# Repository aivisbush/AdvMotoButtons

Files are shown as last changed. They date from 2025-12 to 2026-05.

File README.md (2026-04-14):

# Bush's Moto Buttons v1.0
### Thanks to [the original author](https://github.com/joncox123/MotoButtons2/tree/main) for free sourcing this amazing piece of art, especially the dev board wiring and the code part! So, I needed some modifications to it to move forward to perfection. To continue supporting enduro, offroad, adventure enthusiasts who can also tinker with electronics, and build a relatively inexpensive alternative to moto buttons, I also want to share my work.

### My changes:
- LED brightness control by holding the A key
- Added possibility to add any color or brightness (within code)
- Separate key A and Joystick Center key codes (in original code they were the same)
- DMD2 mode color changed to blue (looks cooler)
- Button special function changes (will be described later)
- Added reset option by holding A,B,C keys. This is a workaround for the issue when Bluetooth auto-pairing did not work anymore, e.g., when the moto buttons are powered on, auto-connection to the phone/tablet does not work

### Design:

| | |
| --- | --- |
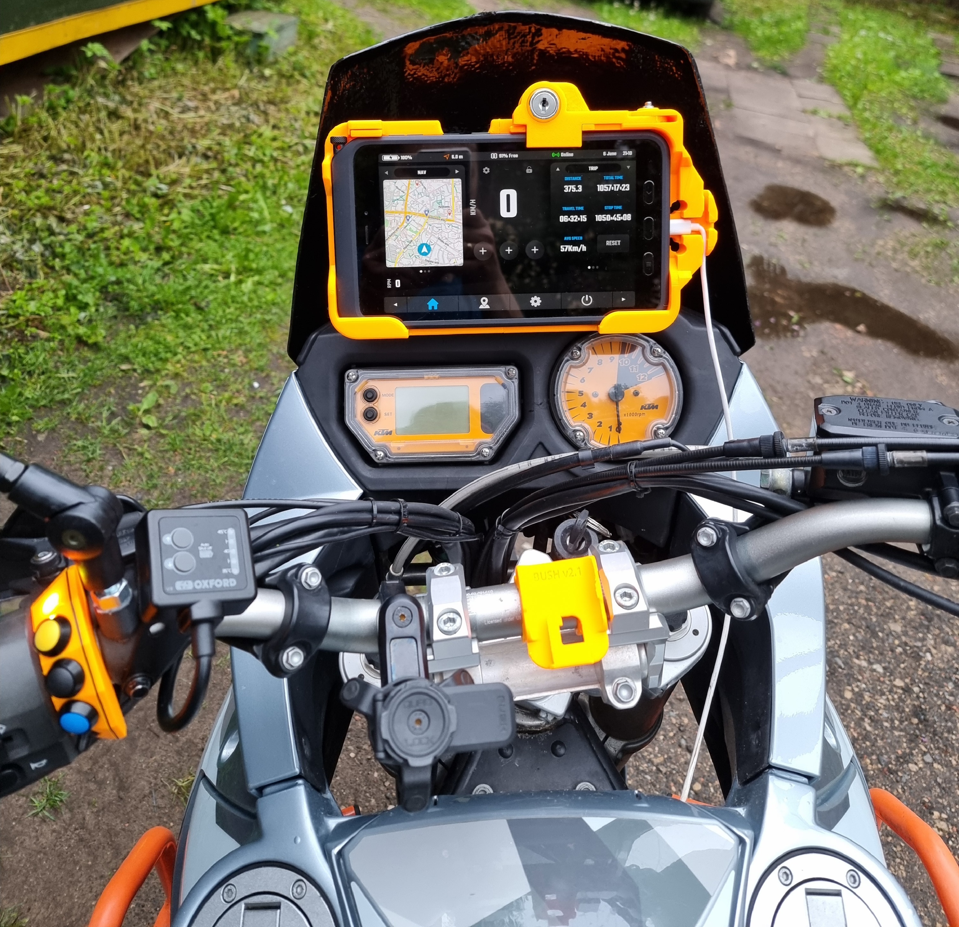
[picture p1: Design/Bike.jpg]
Bike
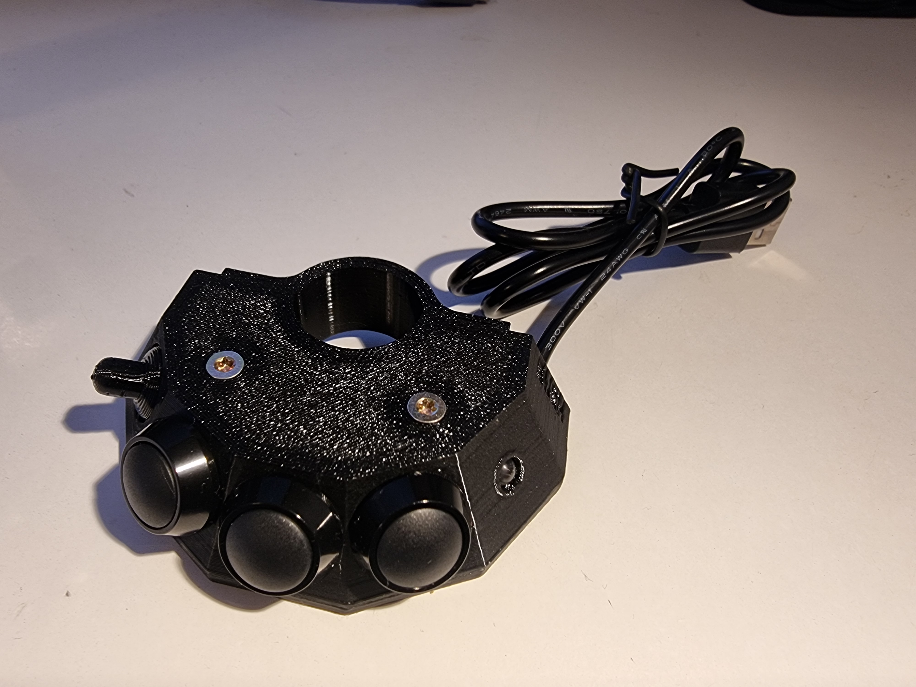
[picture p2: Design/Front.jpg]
Front
|  |  |
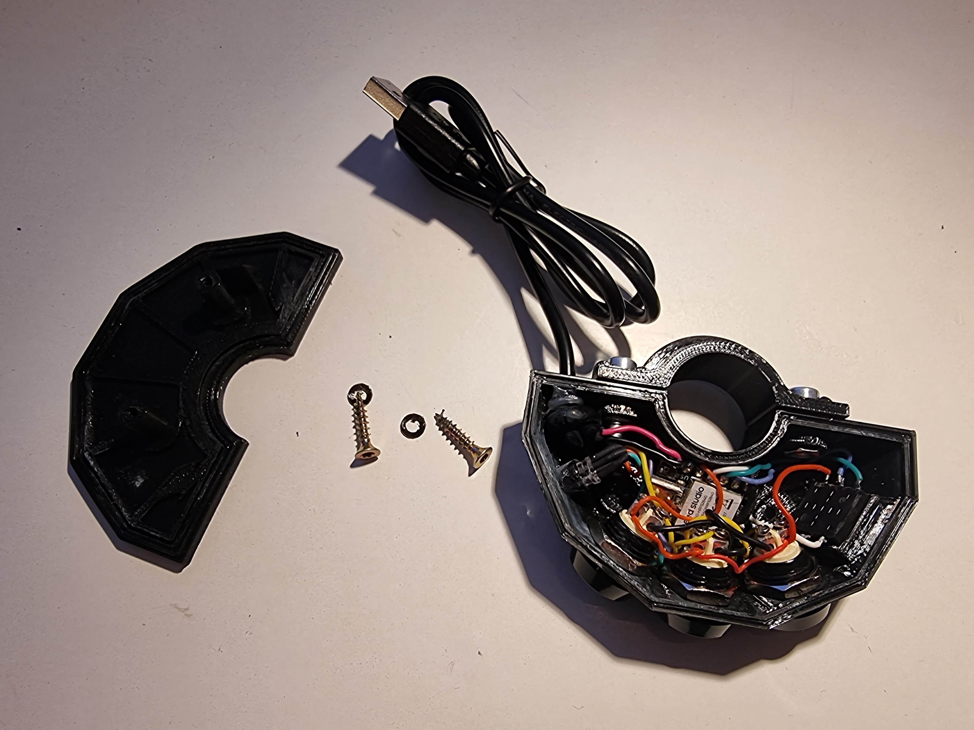
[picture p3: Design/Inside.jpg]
Inside
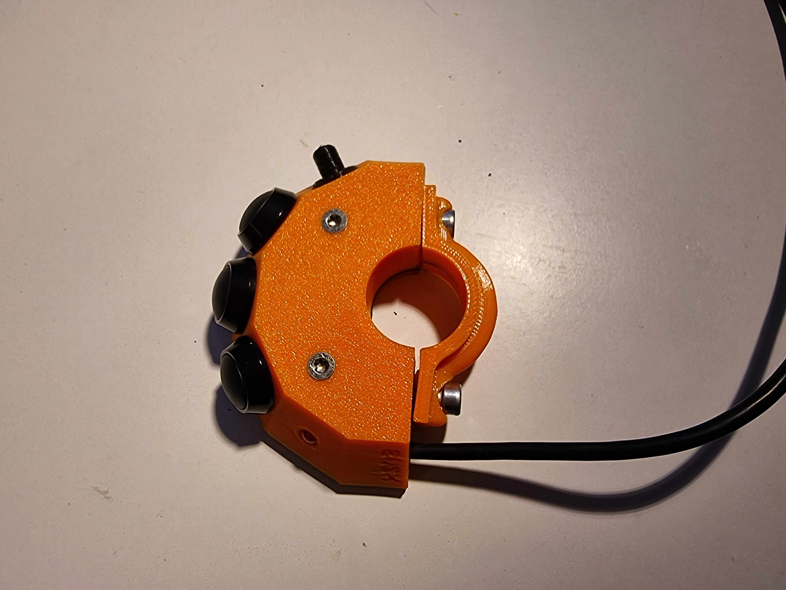
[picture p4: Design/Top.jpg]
Top
|  |  |

### Parts:
- Some old USB-A cable for power and other wires
- Seeed Studio XIAO nRF52840 series (I used Seeed Studio XIAO nRF52840 Sense)
- 3x waterproof buttons (I used V12B-10N-A)
- 5-way joystick (I used JS5208)
- RGB LED common **anode ONLY** (I used OSTAMA5B31A) **Do not use common cathode, I already burned 2x Seeed boards to realize that**
- 3D printed case with some screws (the case is waterproof enough to hold rain and some submersion. I've already been using it for 1 year, no issues. But use some super glue on the TPU gasket and glue gun around holes from inside). All TPU and PETG (or alternative filament) STLs are in 3D folder.

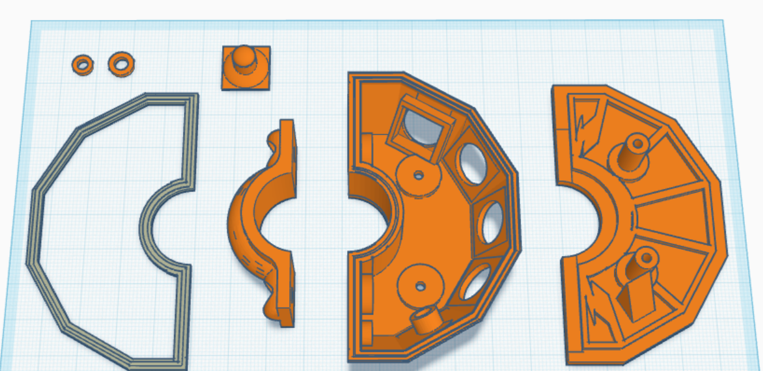
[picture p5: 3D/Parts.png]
Parts


## User Manual
The device has:
- 3x buttons and 1x joystick as inputs
- 1x LED indicator (for understanding what is going on)

Standard button functionality by mode:

`DMD2` mode (**NOTE**: bound buttons manually in Settings -> Setup Remote Controller):
- Button A short press or hold - `F6` / oom in
- Button B short press or hold - `F7` / zoom out
- Button C short press or hold - `Enter` / follow toggle (focus)
- Joystick Up, Down, Left, Right - Arrow keys
- Joystick Middle press - `F8`

`OsmAnd` mode:
- Button A short press or hold - `+` / zoom in
- Button B short press or hold - `-` / zoom out
- Button C short press or hold - `C` / move to my location (focus)
- Joystick Up, Down, Left, Right - Arrow keys
- Joystick Middle press - Unbound

`Media` mode:
- Button A short press or hold - Play / Pause
- Button B short press or hold - Screen brightness up
- Button C short press or hold - Screen brightness down
- Joystick Up - Volume up
- Joystick Down - Volume down
- Joystick Left - Previous track
- Joystick Right - Next track
- Joystick Middle press - Mute

Special functions:
- Hold joystick up button when powering on device, it will select correct orientation
- Button A+B long press - LED brightness changes; hold it until you are satisfied and release
- Button B+C long press - Mode change: DMD2 (blue) -> OsmAnd (green) -> Media (magenta)
- Button A+B+C long press (5 secs) - Erase FS. This is a workaround to get BT auto-connect working again
- Button A+C long press (5 secs) - Enter DFU mode (for programming)

## Wiring
If something is unclear, please read [the original author's manuals](https://github.com/joncox123/MotoButtons2/tree/main/ConstructionGuide).
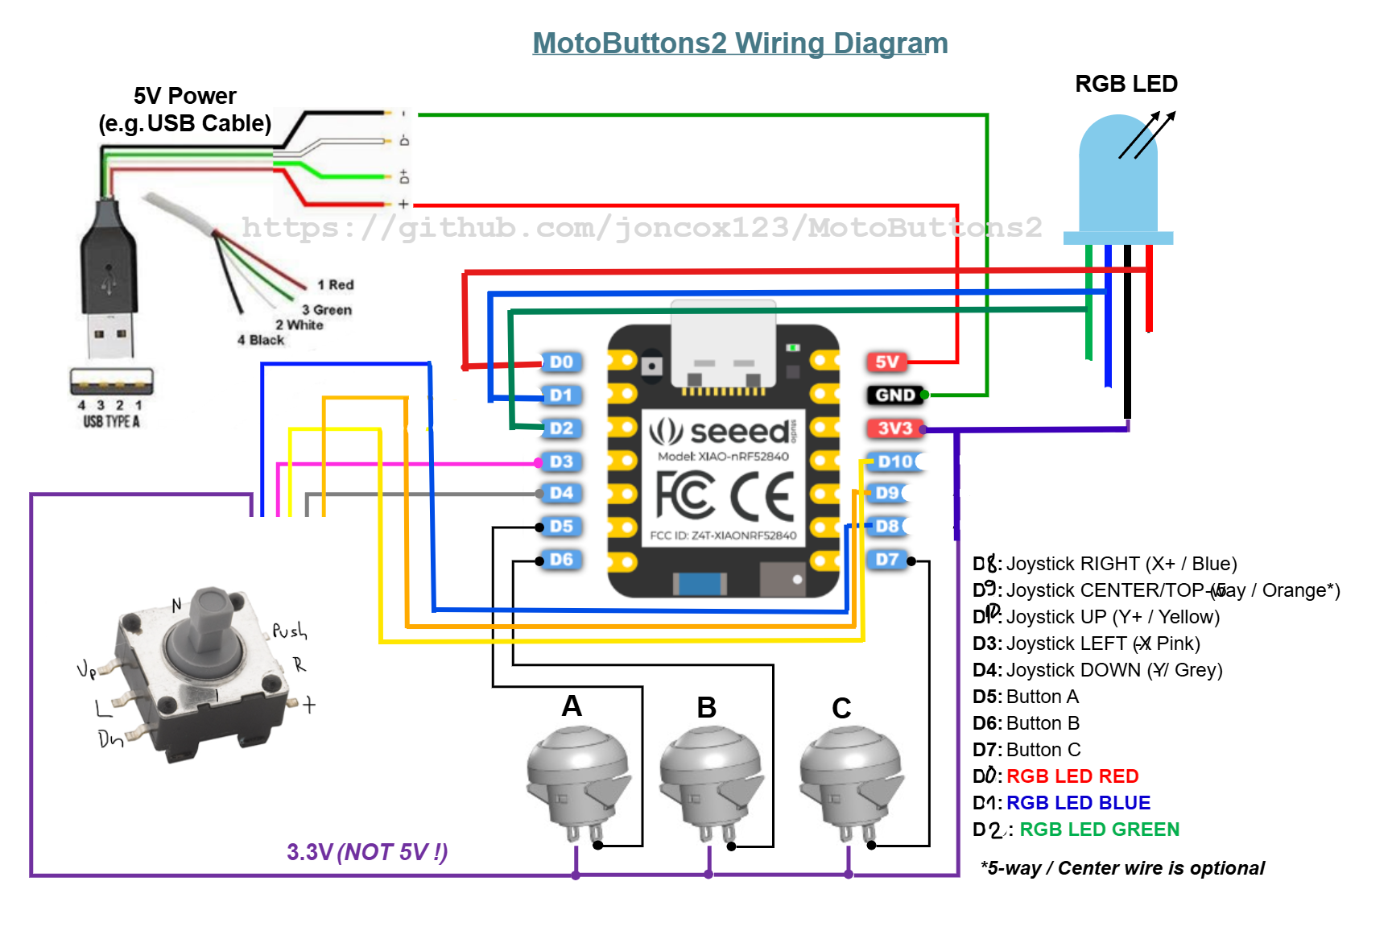
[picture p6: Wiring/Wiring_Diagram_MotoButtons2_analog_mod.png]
Wiring Diagram


## Code
Please read [the original author's manuals](https://github.com/joncox123/MotoButtons2/tree/main/Programming) on how to do that.

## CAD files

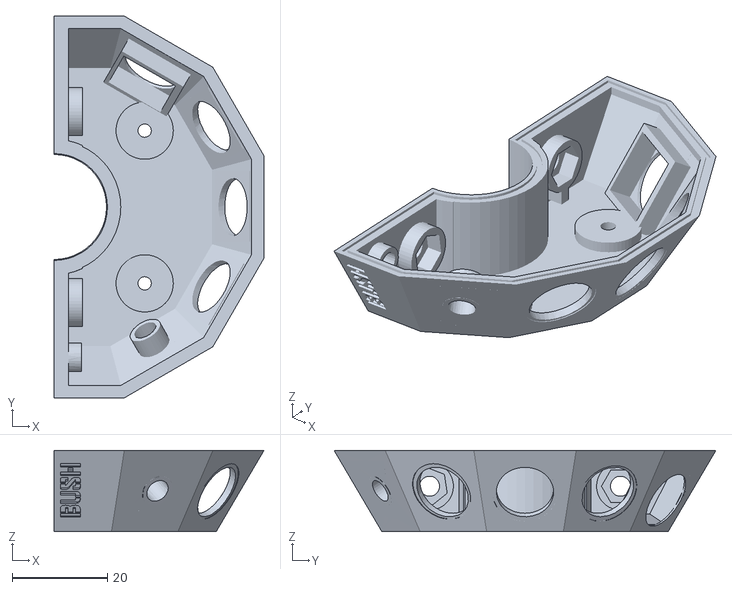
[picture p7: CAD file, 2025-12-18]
3D/Case_main_PETG.stl
44.0 x 80.0 x 17.0

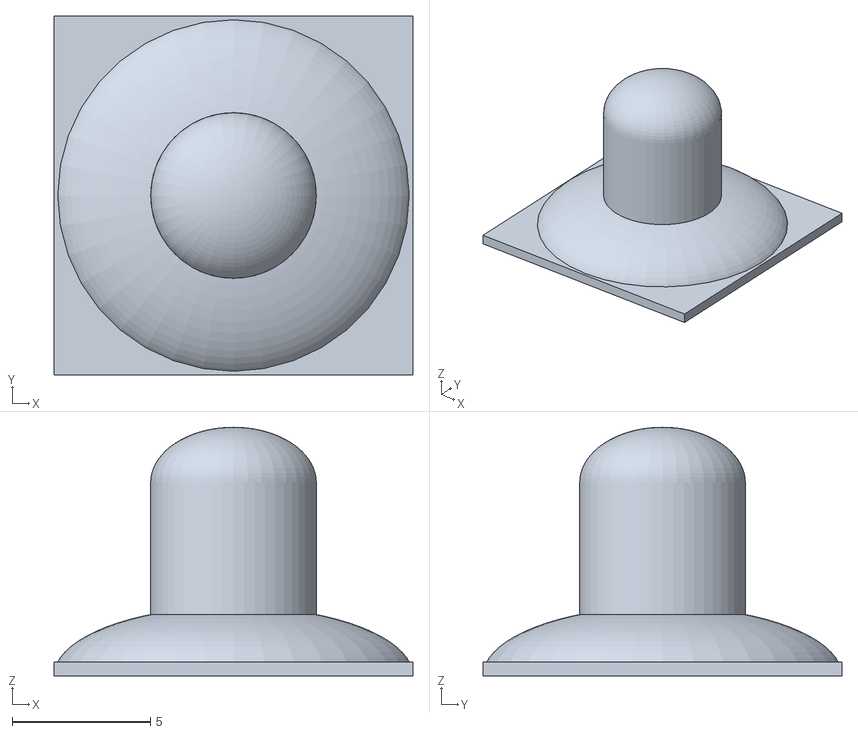
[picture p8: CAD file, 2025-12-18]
3D/Joystick_cover_TPU.stl
13.0 x 13.0 x 9.00

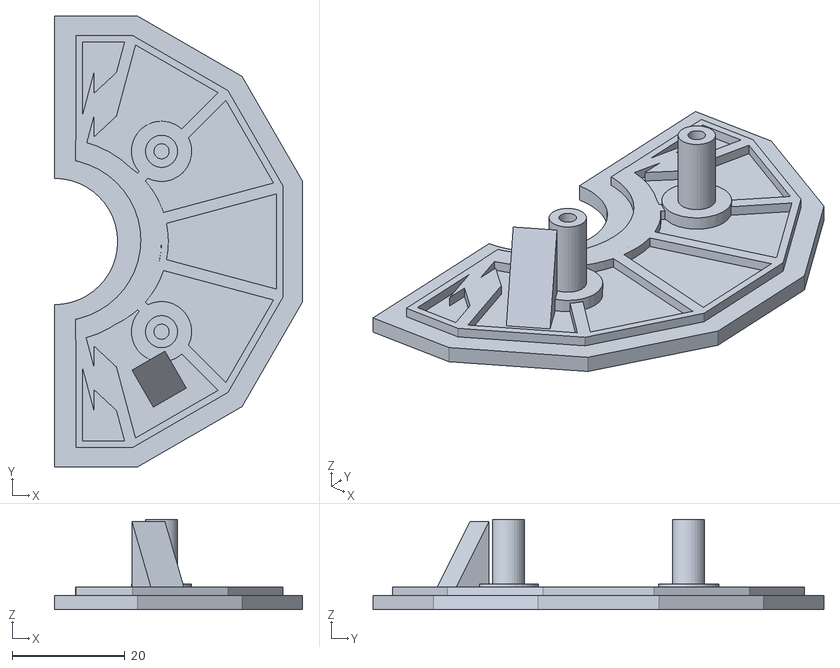
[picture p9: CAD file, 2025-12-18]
3D/Case_top_PETG.stl
44.0 x 80.0 x 16.0

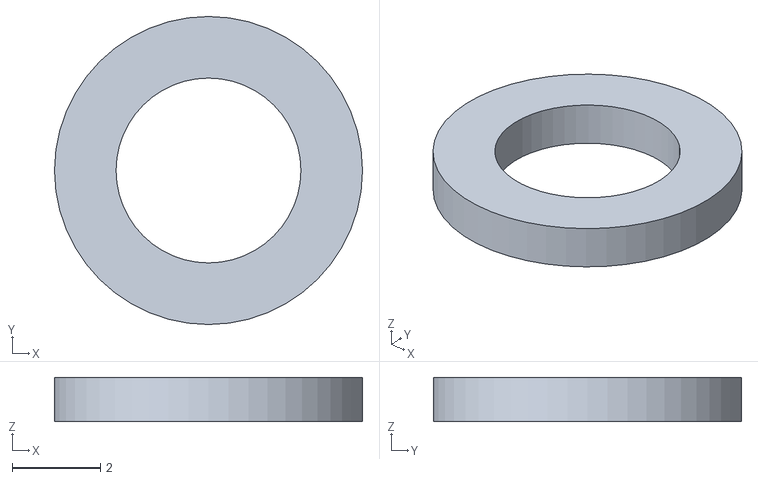
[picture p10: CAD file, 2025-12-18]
3D/SpacerA_TPU.stl
7.00 x 7.00 x 1.00

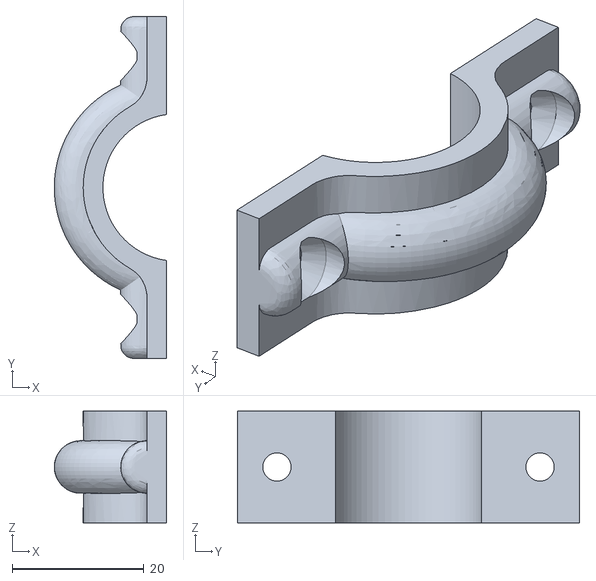
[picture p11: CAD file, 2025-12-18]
3D/Handlebar_back_PETG.stl
17.1 x 52.0 x 17.0

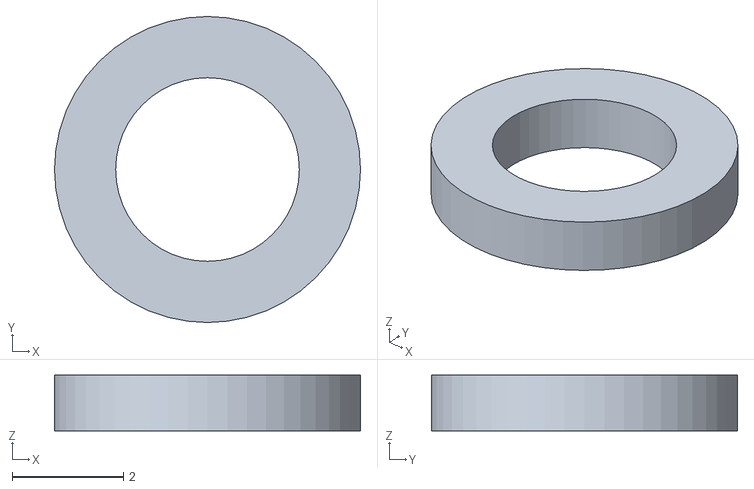
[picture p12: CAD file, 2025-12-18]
3D/SpacerB_TPU.stl
5.50 x 5.50 x 1.00

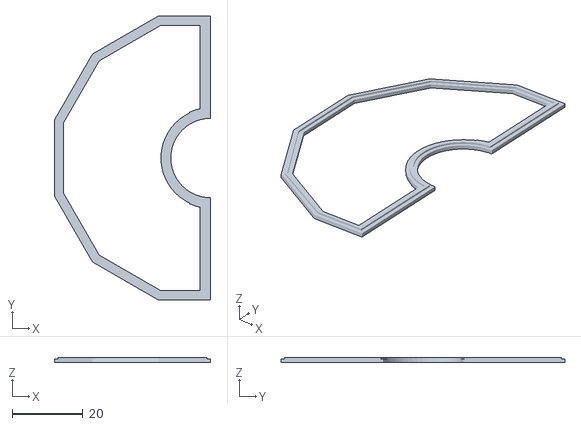
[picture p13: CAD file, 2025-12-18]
3D/Gasket_TPU.stl
44.0 x 80.0 x 1.50

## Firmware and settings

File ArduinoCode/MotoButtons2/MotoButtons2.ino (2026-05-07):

/*********************************************************************
License: GNU GENERAL PUBLIC LICENSE; Version 3, 29 June 2007
Version: 2.0 with support for the following modes: DMD2, OsmAnd, media (music)
Device: Seeed XIAO ESP32-C6 (MotoButtons 2)
*********************************************************************/
#include <HijelHID_BLEKeyboard.h>
#include <Preferences.h>
#include <stdlib.h>

// Enable serial debugging (turn this off if not connected to PC)
#define DEBUG false

// How long to wait until the reset combo is activated
#define MODE_RESET_MS 5000

// Orientation of controller
#define DEFAULT_BUTTON_MAP 3
#define STARTUP_ORIENTATION_WINDOW_MS 500
uint8_t buttonOrientation = DEFAULT_BUTTON_MAP;

/*----- Persistent Storage -----*/
// This is used to store settings, such as the last mode.
Preferences preferences;
const char SETTINGS_NAMESPACE[] = "MotoButtons";

// BLE configuration
#define BLE_TX_POWER 8
const char BLE_DEVICE_NAME[] = "Bush Moto BT7";
const char BLE_DEVICE_MODEL[] = "Btns v2.0";
const char BLE_MANUFACTURER[] = "Bush";
bool BLE_connected = false;

// BLE classes
HijelHID_BLEKeyboard bleKeyboard(BLE_DEVICE_NAME, BLE_MANUFACTURER, 100);

// RGB LED colors plus off
typedef enum
{
  Red,
  Blue,    // BLE connected (flashing, BLE not connected)
  Green,   // OsmAnd mode
  Magenta, // media mode
  White,   // regular key press
  Off,
} Color;

Color priorLEDState = Off;
Color LEDState = Off;

#define BLE_COLOR Blue
#define DMD2_MODE_COLOR Blue
#define OSMAND_MODE_COLOR Green
#define MEDIA_MODE_COLOR Magenta
#define KEY_PRESS_COLOR White
#define POWER_ON_COLOR Red
#define SETUP_COMPLETE_COLOR White
#define BUTTON_ORIENTATION_COLOR Red

/*
 * --------------------- MODE CONFIGURATION ----------------------------
 * 	DMD2: up/down/left/right arrows, enter, F6 and F7
 * 	OsmAnd: up/down/left/right arrows, unbound center, '+', '-', 'c'
 *  Media (music): vol up, vol down, previous track, next track, mute, play/pause, stop
 */
// Selected Mode: indicates the currently selected operating mode
#define MODE_TOGGLE_MS 1000
#define N_MODES 3
typedef enum
{
  DMD2 = 1,
  OsmAnd = 2,
  MEDIA = 3
} Mode;
#define DEFAULT_MODE DMD2
Mode currentMode;

bool modeButtonsReleased = true;
bool modeComboConsumed = false;
bool formatComboConsumed = false;
bool brightnessSettingsDirty = false;

/* DMD2 Mode Configuration */
// https://www.drivemodedashboard.com/controller-implementation-guide/
// Key codes to send for button presses:
const uint8_t DMD_KEY_UP = KEY_UP;
const uint8_t DMD_KEY_DOWN = KEY_DOWN;
const uint8_t DMD_KEY_LEFT = KEY_LEFT;
const uint8_t DMD_KEY_RIGHT = KEY_RIGHT;
const uint8_t DMD_KEY_CENTER = KEY_F8;
const uint8_t DMD_KEY_A = KEY_F6;
const uint8_t DMD_KEY_B = KEY_F7;
const uint8_t DMD_KEY_C = KEY_RETURN;

/* OsmAnd Mode Configuration */
const uint8_t OSMAND_KEY_UP = KEY_UP;
const uint8_t OSMAND_KEY_DOWN = KEY_DOWN;
const uint8_t OSMAND_KEY_LEFT = KEY_LEFT;
const uint8_t OSMAND_KEY_RIGHT = KEY_RIGHT;
const uint8_t OSMAND_KEY_CENTER = KEY_NONE;           // unbound
const uint8_t OSMAND_KEY_A = KEY_EQUAL;               // zoom in (+ key)
const uint8_t OSMAND_KEY_B = KEY_MINUS;               // zoom out
const uint8_t OSMAND_KEY_C = KEY_C;                   // move to my location

/* Media Mode Configuration */
const uint16_t MEDIA_KEY_UP = MEDIA_VOLUME_UP;        // volume up
const uint16_t MEDIA_KEY_DOWN = MEDIA_VOLUME_DOWN;    // volume down
const uint16_t MEDIA_KEY_LEFT = MEDIA_PREV_TRACK;     // previous song
const uint16_t MEDIA_KEY_RIGHT = MEDIA_NEXT_TRACK;    // next song
const uint16_t MEDIA_KEY_CENTER = MEDIA_MUTE;         // Mute
const uint16_t MEDIA_KEY_A = MEDIA_PLAY_PAUSE;        // play - pause
const uint16_t MEDIA_KEY_B = MEDIA_BRIGHTNESS_UP;     // increase brightness
const uint16_t MEDIA_KEY_C = MEDIA_BRIGHTNESS_DOWN;   // decrease brightness
/*---------------------- END MODE CONFIGURATION ----------------------*/

/*----------------- BUTTON CONFIGURATION AND LOGIC -------------------*/
/* BLE key report */
#define N_KEY_REPORT 6
uint8_t keyReport[N_KEY_REPORT] = {KEY_NONE, KEY_NONE, KEY_NONE, KEY_NONE, KEY_NONE, KEY_NONE};
bool keyReportChanged = false;
bool forceKeyReport = false; // used to force another key report for key up activation events

// Digital IO pin mapping (default)
uint8_t BUTTON_UP = D3;
uint8_t BUTTON_DOWN = D8;
uint8_t BUTTON_LEFT = D4;
uint8_t BUTTON_RIGHT = D10;
uint8_t BUTTON_CENTER = D9;
uint8_t BUTTON_A = D5;
uint8_t BUTTON_B = D6;
uint8_t BUTTON_C = D7;
uint8_t RGB_LED_RED = D0;
uint8_t RGB_LED_GREEN = D1;
uint8_t RGB_LED_BLUE = D2;
#define USER_LED_PIN LED_BUILTIN
#define USER_LED_ACTIVE_LOW true

// Raw joystick GPIOs used for startup orientation selection.
const uint8_t JOYSTICK_PIN_UP = D4;
const uint8_t JOYSTICK_PIN_DOWN = D10;
const uint8_t JOYSTICK_PIN_LEFT = D8;
const uint8_t JOYSTICK_PIN_RIGHT = D3;

#define DEBOUNCE_TIME_MS 50
#define DIRECTION_REPEAT_INTERVAL_MS 100
#define ABC_REPEAT_INTERVAL_MS 250
#define DMD_ABC_REPEAT_INTERVAL_MS 100
// state of buttons
bool button_up_state = false;
bool button_down_state = false;
bool button_left_state = false;
bool button_right_state = false;
bool button_center_state = false;
bool button_A_state = false;
bool button_B_state = false;
bool button_C_state = false;
// prior state of button reading for debouncing purposes
bool button_up_state_prior = false;
bool button_down_state_prior = false;
bool button_left_state_prior = false;
bool button_right_state_prior = false;
bool button_center_state_prior = false;
bool button_A_state_prior = false;
bool button_B_state_prior = false;
bool button_C_state_prior = false;

// Record state change of buttons to be used to monitor when event is transmitted
bool button_up_flipped = false;
bool button_down_flipped = false;
bool button_left_flipped = false;
bool button_right_flipped = false;
bool button_center_flipped = false;
bool button_A_flipped = false;
bool button_B_flipped = false;
bool button_C_flipped = false;
// last time that button transitioned from low to high
unsigned long button_up_time = 0;
unsigned long button_down_time = 0;
unsigned long button_left_time = 0;
unsigned long button_right_time = 0;
unsigned long button_center_time = 0;
unsigned long button_A_time = 0;
unsigned long button_B_time = 0;
unsigned long button_C_time = 0;
// LED brightness 0 - 255 (100% - 0%)
int LEDbrightness = 0;
unsigned long brightnessAdjustTime = 0;
bool brightnessComboConsumed = false;
unsigned long lastKeyRepeatTime = 0;
/*------------------- END BUTTON CONFIG & LOGIC-----------------------*/

void setUserLED(bool on)
{
  digitalWrite(USER_LED_PIN, (USER_LED_ACTIVE_LOW ? !on : on) ? HIGH : LOW);
}

/*
  Set the color of the RGB LED to one of the 7 possibilities, plus off
  For a common anode(+) LED, LOW is ON and HIGH is OFF.
*/
void setRGBColor(Color color)
{
  priorLEDState = LEDState;

  // convert a "normal" 0..255 channel intensity into the common-anode
  // analogWrite value, taking LEDbrightness (0..255, 0==full on, 255==off) into account.
  auto rgbAnalog = [](uint8_t channel)->uint8_t {
    // brightnessPercent = (255 - LEDbrightness)/255
    // analog = 255 - channel * brightnessPercent
    return (uint8_t)(255 - (((uint16_t)channel * (255 - LEDbrightness) + 127) / 255));
  };

  switch (color)
  {
  case Red:
    LEDState = Red;
    analogWrite(RGB_LED_RED, rgbAnalog(255));
    analogWrite(RGB_LED_BLUE, rgbAnalog(0));
    analogWrite(RGB_LED_GREEN, rgbAnalog(0));
    break;
  case Blue:
    LEDState = Blue;
    analogWrite(RGB_LED_RED, rgbAnalog(0));
    analogWrite(RGB_LED_BLUE, rgbAnalog(255));
    analogWrite(RGB_LED_GREEN, rgbAnalog(0));
    break;
  case Green:
    LEDState = Green;
    analogWrite(RGB_LED_RED, rgbAnalog(0));
    analogWrite(RGB_LED_BLUE, rgbAnalog(0));
    analogWrite(RGB_LED_GREEN, rgbAnalog(255));
    break;
  case Magenta:
    LEDState = Magenta;
    // keep existing slight-dim behavior (~245) for magenta
    analogWrite(RGB_LED_RED, rgbAnalog(245));
    analogWrite(RGB_LED_BLUE, rgbAnalog(245));
    analogWrite(RGB_LED_GREEN, rgbAnalog(0));
    break;
  case White:
    LEDState = White;
    // keep existing slight-dim behavior (~245) for white
    analogWrite(RGB_LED_RED, rgbAnalog(245));
    analogWrite(RGB_LED_BLUE, rgbAnalog(245));
    analogWrite(RGB_LED_GREEN, rgbAnalog(245));
    break;
  case Off:
  default:
    LEDState = Off;
    analogWrite(RGB_LED_RED, rgbAnalog(0));
    analogWrite(RGB_LED_BLUE, rgbAnalog(0));
    analogWrite(RGB_LED_GREEN, rgbAnalog(0));
  }

  setUserLED(LEDState != Off && LEDbrightness < 255);
}

void flashLED(Color color, uint16_t delayMs, uint16_t durationMs)
{
  uint8_t N = durationMs / delayMs;

  priorLEDState = LEDState;
  LEDState = color;

  for (uint8_t i = 0; i < 2 * (N + 1); i++)
  {
    if (i % 2 == 0)
      setRGBColor(Off);
    else
      setRGBColor(color);
    delay(delayMs / 2);
  }
}

void restoreLEDState()
{
  setRGBColor(priorLEDState);
  LEDState = priorLEDState;
}

void indicateMode(Mode mode)
{
  // Indicate the new mode
  switch (mode)
  {
  case DMD2:
    flashLED(DMD2_MODE_COLOR, 1000, 200);
    setRGBColor(DMD2_MODE_COLOR);
    break;
  case OsmAnd:
    flashLED(OSMAND_MODE_COLOR, 1000, 200);
    setRGBColor(OSMAND_MODE_COLOR);
    break;
  case MEDIA:
    flashLED(MEDIA_MODE_COLOR, 1000, 200);
    setRGBColor(MEDIA_MODE_COLOR);
    break;
  default:
    setRGBColor(Red);
  }
}

void showMode(Mode mode)
{
  // Indicate the new mode
  switch (mode)
  {
  case DMD2:
    setRGBColor(DMD2_MODE_COLOR);
    break;
  case OsmAnd:
    setRGBColor(OSMAND_MODE_COLOR);
    break;
  case MEDIA:
    setRGBColor(MEDIA_MODE_COLOR);
    break;
  default:
    setRGBColor(Red);
  }
}

void RGBToggle(Color color)
{
  // Treat LED as "on" when a color (not Off) is active.
  if (LEDState == Off)
    setRGBColor(color);
  else
    setRGBColor(Off);
}

// cycle through all colors of the LED for demo purposes
void colorCycle(uint16_t N)
{
  const uint8_t COLOR_COUNT = 6;
  for (uint32_t i = 0; i < N * COLOR_COUNT; i++)
  {
    setRGBColor((Color)(i % COLOR_COUNT));
    delay(500);
  }
}

// At startup, the user can hold down a joystick direction to select an orientation
// -1 indicates no valid selection was made
int getButtonMapSelection()
{
  unsigned long startMs = millis();
  int detectedSelection = -1;

  while (millis() - startMs < STARTUP_ORIENTATION_WINDOW_MS)
  {
    // Read all four directions because we can only allow a mode switch if
    // one direction is pressed
    uint8_t up = digitalRead(JOYSTICK_PIN_UP);
    uint8_t down = digitalRead(JOYSTICK_PIN_DOWN);
    uint8_t left = digitalRead(JOYSTICK_PIN_LEFT);
    uint8_t right = digitalRead(JOYSTICK_PIN_RIGHT);

    if (up + down + left + right > 1)
      return -1;

    if (up)
      detectedSelection = 2;
    else if (down)
      detectedSelection = 0;
    else if (left)
      detectedSelection = 1;
    else if (right)
      detectedSelection = 3;

    if (detectedSelection >= 0)
      return detectedSelection;

    delay(10);
  }

  // no selection was made during the startup window
  return -1;
}

/* Change the mapping of buttons based on a map specifier, buttMap
 * butMapp:
 * 	0: UP is GPIO pin 2
 *  1: UP is GPIO pin 3
 *  2: UP is GPIO pin 4
 *  3: UP is GPIO pin 0
 */
bool setButtonMapping(uint8_t buttMap)
{
  switch (buttMap)
  {
  case 0: // three buttons on top
    BUTTON_UP = D10;
    BUTTON_DOWN = D4;
    BUTTON_LEFT = D3;
    BUTTON_RIGHT = D8;
    BUTTON_CENTER = D9;
    BUTTON_A = D5;
    BUTTON_B = D6;
    BUTTON_C = D7;
    break;
  case 1: // three buttons on left
    BUTTON_UP = D8;
    BUTTON_DOWN = D3;
    BUTTON_LEFT = D10;
    BUTTON_RIGHT = D4;
    BUTTON_CENTER = D9;
    BUTTON_A = D5;
    BUTTON_B = D6;
    BUTTON_C = D7;
    break;
  case 2: // three buttons on bottom
    BUTTON_UP = D4;
    BUTTON_DOWN = D10;
    BUTTON_LEFT = D8;
    BUTTON_RIGHT = D3;
    BUTTON_CENTER = D9;
    BUTTON_A = D5;
    BUTTON_B = D6;
    BUTTON_C = D7;
    break;
  case 3: // three buttons toward right
    BUTTON_UP = D3;
    BUTTON_DOWN = D8;
    BUTTON_LEFT = D4;
    BUTTON_RIGHT = D10;
    BUTTON_CENTER = D9;
    BUTTON_A = D5;
    BUTTON_B = D6;
    BUTTON_C = D7;
    break;
  default:
    return true;
  }

  return false;
}

// This function returns true if the center button is in an active state
// if so, the program should ignore up/down/left/right on the joystick
bool isCenterActive()
{
  if (button_center_state)
    return true;
  if (digitalRead(BUTTON_CENTER))
    return true;

  return false;
}

// if  This function should be called rapidly in a loop to update the debounce filter and key state
//  https://docs.arduino.cc/built-in-examples/digital/Debounce
bool debounceButton(unsigned int button, bool *state, bool *priorState, bool *buttonFlipped,
                    unsigned long *debounceTime, const char *buttonName)
{
  bool reading;
  unsigned long readTime;
  bool stateChanged = false;

  reading = digitalRead(button);
  readTime = millis();

  // If reading has changed, switch has not settled yet
  if (reading != *priorState)
    *debounceTime = readTime;
  // State has been stable for time exceeding debounce filter delay, so update state
  else if ((readTime - *debounceTime) > DEBOUNCE_TIME_MS)
    // If state changed after debounce, new state has not yet been transmitted
    if (reading != *state)
    {
      stateChanged = true;
      *state = reading;
      *buttonFlipped = true;
      if (DEBUG)
      {
        Serial.print("Button ");
        Serial.print(buttonName);
        Serial.println(reading ? " pressed" : " released");
      }
    }
  *priorState = reading;

  return stateChanged;
}

void releaseAllKeys()
{
  bleKeyboard.releaseAll();
}

void sendKeyboardReport()
{
  bleKeyboard.releaseAll();
  for (uint8_t i = 0; i < N_KEY_REPORT; i++)
  {
    if (keyReport[i] != KEY_NONE)
      bleKeyboard.press(keyReport[i]);
  }
}

void applyDefaultSettings()
{
  currentMode = DEFAULT_MODE;
  buttonOrientation = DEFAULT_BUTTON_MAP;
  LEDbrightness = 0;
  setButtonMapping(buttonOrientation);
}

void clearABCButtonFlips()
{
  button_A_flipped = false;
  button_B_flipped = false;
  button_C_flipped = false;
}

Mode getNextMode(Mode mode)
{
  switch (mode)
  {
  case DMD2:
    return OsmAnd;
  case OsmAnd:
    return MEDIA;
  case MEDIA:
  default:
    return DMD2;
  }
}

bool parseUint8Token(const char *token, int minValue, int maxValue, uint8_t *outValue)
{
  if (token == NULL)
    return false;

  char *endPtr = NULL;
  long parsed = strtol(token, &endPtr, 10);
  if (endPtr == token || *endPtr != '\0' || parsed < minValue || parsed > maxValue)
    return false;

  *outValue = (uint8_t)parsed;
  return true;
}

bool handleFormatCombo(bool stateChanged)
{
  bool formatButtonsPressed = button_A_state && button_B_state && button_C_state;
  if (!formatButtonsPressed)
    return false;

  // The filesystem format combo takes priority over all smaller button combos.
  releaseAllKeys();
  clearABCButtonFlips();
  modeButtonsReleased = false;
  modeComboConsumed = false;
  brightnessAdjustTime = 0;
  brightnessComboConsumed = false;
  brightnessSettingsDirty = false;
  keyReportChanged = stateChanged;

  if (!formatComboConsumed &&
      (millis() - button_A_time > MODE_RESET_MS) &&
      (millis() - button_B_time > MODE_RESET_MS) &&
      (millis() - button_C_time > MODE_RESET_MS))
  {
    if (DEBUG)
      Serial.println("Clearing saved settings...");
    preferences.begin(SETTINGS_NAMESPACE, false);
    preferences.clear();
    preferences.end();
    applyDefaultSettings();
    writeSettings();
    flashLED(Red, 500, 2000);
    indicateMode(currentMode);
    formatComboConsumed = true;
  }
  return true;
}

bool handleConsumedFormatCombo(bool stateChanged)
{
  if (!formatComboConsumed)
    return false;

  clearABCButtonFlips();
  keyReportChanged = stateChanged;
  if (!button_A_state && !button_B_state && !button_C_state)
    formatComboConsumed = false;
  return true;
}

void handleModeCycleCombo()
{
  if (!button_B_state || !button_C_state)
    modeButtonsReleased = true;

  if (button_B_state && button_C_state && !button_A_state &&
      (millis() - max(button_B_time, button_C_time) > MODE_TOGGLE_MS) &&
      modeButtonsReleased)
  {
    currentMode = getNextMode(currentMode);
    if (DEBUG)
    {
      Serial.print("Mode advanced to ");
      Serial.println(currentMode);
    }

    releaseAllKeys();
    modeButtonsReleased = false;
    modeComboConsumed = true;
    button_B_flipped = false;
    button_C_flipped = false;
    writeSettings();
    indicateMode(currentMode);
  }
  else if (modeComboConsumed)
  {
    button_B_flipped = false;
    button_C_flipped = false;
    if (!button_B_state && !button_C_state)
      modeComboConsumed = false;
  }
}

void handleBrightnessCombo()
{
  if (button_A_state && button_B_state)
  {
    unsigned long brightnessHoldMs = millis() - max(button_A_time, button_B_time);
    if (brightnessHoldMs > MODE_TOGGLE_MS && (brightnessAdjustTime == 0 || millis() - brightnessAdjustTime >= 200))
    {
      LEDbrightness = LEDbrightness - 20;
      if (LEDbrightness < 0)
        LEDbrightness = 255;
      brightnessAdjustTime = millis();
      brightnessComboConsumed = true;
      brightnessSettingsDirty = true;
      button_A_flipped = false;
      button_B_flipped = false;

      setRGBColor(LEDState);
      if (DEBUG)
      {
        Serial.print("LED brightness changed to ");
        Serial.println(LEDbrightness);
      }
    }
  }
  else
  {
    brightnessAdjustTime = 0;
    if (brightnessComboConsumed)
    {
      button_A_flipped = false;
      button_B_flipped = false;
      if (!button_A_state && !button_B_state)
      {
        brightnessComboConsumed = false;
        if (brightnessSettingsDirty)
        {
          writeSettings();
          brightnessSettingsDirty = false;
        }
      }
    }
  }
}

bool hasRepeatableKeyHold()
{
  bool centerActive = isCenterActive();

  switch (currentMode)
  {
  case DMD2:
    if (!centerActive &&
        (button_up_state || button_down_state || button_left_state || button_right_state))
      return true;

    return (button_A_state && !button_B_state && !button_C_state) ||
           (button_B_state && !button_A_state && !button_C_state) ||
           (button_C_state && !button_A_state && !button_B_state);

  case OsmAnd:
    if (!centerActive &&
        (button_up_state || button_down_state || button_left_state || button_right_state))
      return true;

    return (button_A_state && !button_B_state && !button_C_state) ||
           (button_B_state && !button_A_state && !button_C_state) ||
           (button_C_state && !button_A_state && !button_B_state);

  default:
    return false;
  }
}

uint16_t getKeyRepeatIntervalMs()
{
  bool centerActive = isCenterActive();
  if (!centerActive &&
      (button_up_state || button_down_state || button_left_state || button_right_state))
    return DIRECTION_REPEAT_INTERVAL_MS;

  if (currentMode == DMD2)
    return DMD_ABC_REPEAT_INTERVAL_MS;

  return ABC_REPEAT_INTERVAL_MS;
}
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
void loop()
{
  // Indicate whether the device is connected and running
  if (!BLE_connected && bleKeyboard.isConnected())
  {
    if (DEBUG)
      Serial.println("BLE connected to host.");
    showMode(currentMode);
    BLE_connected = true;
  }
  else if (!bleKeyboard.isConnected())
  {
    RGBToggle(BLE_COLOR);
    delay(200);

    BLE_connected = false;
  }

  // Read current state of buttons
  updateButtons();

  if (bleKeyboard.isPaired())
  {
    bool repeatSend = false;
    uint16_t keyRepeatIntervalMs = getKeyRepeatIntervalMs();
    if (hasRepeatableKeyHold() && !keyReportChanged && !forceKeyReport &&
        (millis() - lastKeyRepeatTime >= keyRepeatIntervalMs))
    {
      repeatSend = true;
    }

    // Compile the BLE HID key report
    if (keyReportChanged || forceKeyReport || repeatSend)
    {
      if (repeatSend)
      {
        releaseAllKeys();
        delay(5);
      }
      if (forceKeyReport) {
        forceKeyReport = false;
        if (DEBUG)
          Serial.println("Key report forced.");
      }
      mapButtonsToKeyReport();
      sendKeyboardReport();
      lastKeyRepeatTime = millis();
      if (DEBUG)
        Serial.println("Key report sent.");
    }
    else if (!hasRepeatableKeyHold())
    {
      lastKeyRepeatTime = millis();
    }

  }
}

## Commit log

2025-11-22 WIP: Changed RGB pins to analog to control LED brightness by holding A. Changed mode switch to only B. .
2025-11-22 Fixed LED brightness cycle
    Changed LED brightness variable type and adjusted brightness logic.
    [MotoButtons2.ino]
2025-11-22 Arduino IDE path needs additional folder
2025-11-23 Save and restore LED brightness
2025-11-23 Updated Readme of Analog RGB mod wiring
2025-11-23 Fixed setButtonMapping. Disabled debug
    [MotoButtons2.ino]
2025-12-11 Updated wiring diagram with JS5208 joystick
2025-12-17 To fix BT auto-paring, added FS format option by holding A,B,C 10secs
    [MotoButtons2.ino]
2025-12-18 Added missing TPU joystick cover
    [Joystick_cover_TPU.stl]
2026-04-14 Fixed default joystick mapping
    [MotoButtons2.ino]
2026-04-14 Stability improvements. Fixed joystick orientation
    [MotoButtons2.ino]
2026-04-14 Media mode. B - increase and C - decrease device screen brightness
2026-04-14 Replaced MRA mode with OsmAnd defaults
    [MotoButtons2.ino]
2026-04-14 LED color cleanup
2026-05-07 Works with Seeed ESP32-C6
2026-05-07 LED color fix and added joystick and button intervals
    [MotoButtons2.ino]
